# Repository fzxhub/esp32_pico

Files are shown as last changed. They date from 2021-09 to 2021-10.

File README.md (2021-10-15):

# esp32_pico
这是一个使用esp32-pico-d4设计的迷你开发板

## 背景

这是根据[稚晖君的ESP32-PicoDK](https://github.com/peng-zhihui/ESP32-PicoDK)修改的esp32迷你开发板。

## 修改要点

1. 增加所有IO引出，由于板子非常mini，所以在背面设计表贴焊盘，需要使用这些特殊接口时，使用贴片2.54的插针引出后再使用即可。
2. 将CAN使用的插针改为VCC3.3V和GND管脚。然后将CANL和CANH在背面设计表贴焊盘引出，个人CAN使用较少，使用时贴片2.54的插针引出后再使用即可。
3. 修改两排插针之间间距为700mil，更加规范的间距，可以使用面包板等。

## 图片

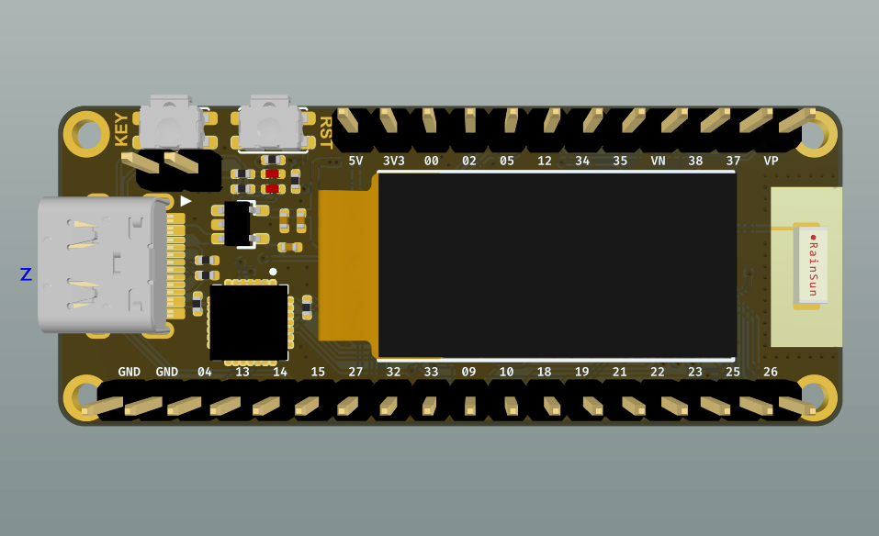
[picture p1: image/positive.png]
正面

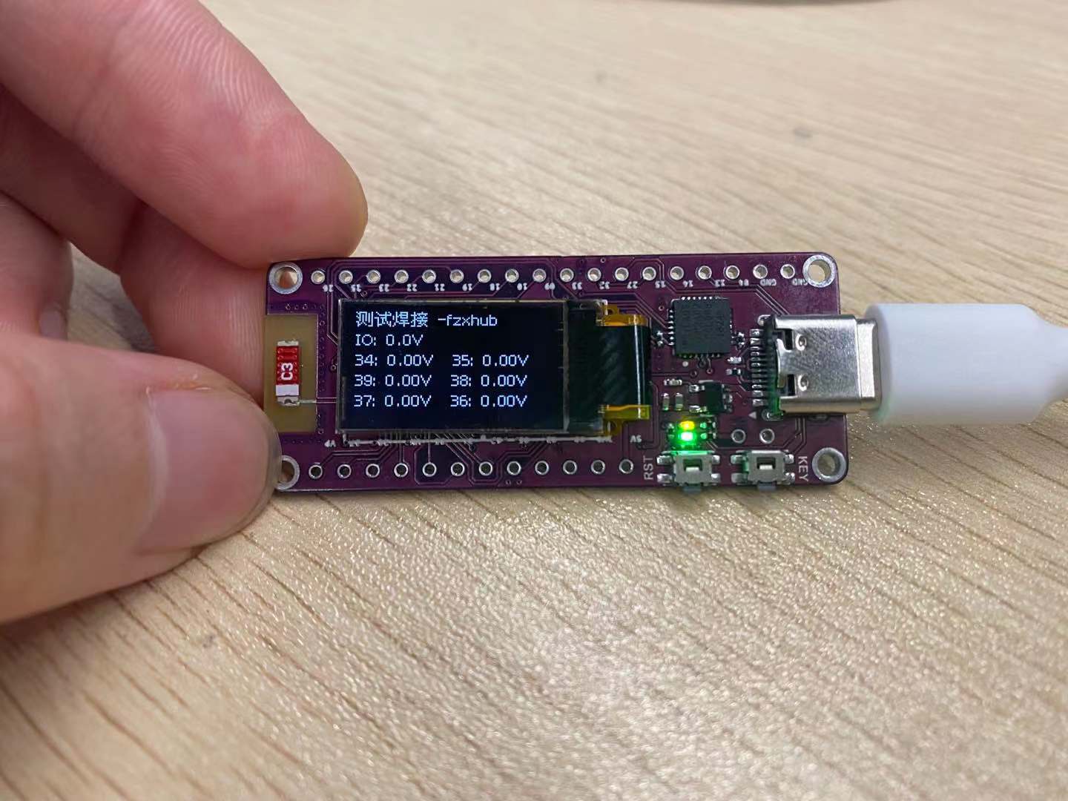
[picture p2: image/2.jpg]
实物


## firmware说明

esp32_pico_test固件是用来测试焊接是否OK的，esp32-pico-d4芯片手工焊接有点难度，需要验证所有IO可以使用。

1. 可以烧录固件表示cp2102，串口IO口：UTX、URX可以使用
2. OLED点亮，表示IO21、IO22可以使用
3. 34，35，39(VN)，38，37，36(VP)只能作为输入，接入模拟信号，屏幕上可以显示电压值
4. 其他IO定时反转，使用万用表可以测量，有定时反转表示OK
5. IO16、IO17、IO11、IO6、IO7、IO8特殊功能不加入测试

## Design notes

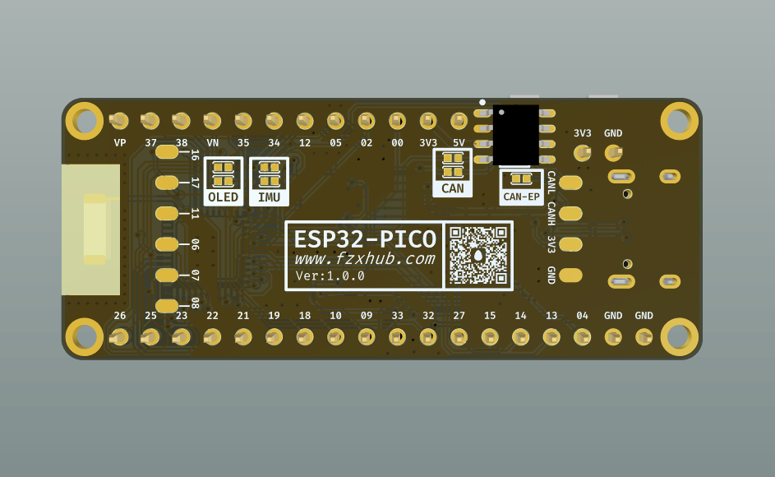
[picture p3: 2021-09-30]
image/reverse.png

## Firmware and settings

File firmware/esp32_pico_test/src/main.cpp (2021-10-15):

#include <Arduino.h>
#include <U8g2lib.h>
#include <Wire.h>

//u8g2库
U8G2_SSD1306_128X80_NONAME_F_HW_I2C u8g2(U8G2_R1, /* reset=*/ U8X8_PIN_NONE, /* clock=*/ 22, /* data=*/21);

//IO口，做输出
int allio[] = {0,2,5,12,4,13,14,15,27,32,33,9,10,18,19,23,25,26};
//I口，输入
int alli[] = {34,35,39,38,37,36};
//输出值
int value = 1;
//输出值反转计数标志
int time_flag = 0;

void setup(void)
{
    //u8g2库
    u8g2.begin();
    u8g2.enableUTF8Print(); 
    //IO口，做输出
    for(int i = 0; i < sizeof(allio)/sizeof(allio[0]); i++)
    {
        pinMode(allio[i], OUTPUT);
    } 
    //I口，输入
    for(int i = 0; i < sizeof(alli)/sizeof(alli[0]); i++)
    {
        pinMode(alli[i], INPUT);
    }
    //u8g2库设置
    u8g2.setFont(u8g2_font_wqy12_t_gb2312);
    u8g2.setFontDirection(0);
}

void loop(void)
{
    //清除缓存
    u8g2.clearBuffer();

    //显示标题
    u8g2.setCursor(0, 10);
    u8g2.print("测试焊接 -fzxhub"); 

    //计数
    time_flag++;
    if(time_flag >= 10) 
    {
        value = !value; 
        time_flag = 0;
    }

    //输出
    for(int i = 0; i < sizeof(allio)/sizeof(alli[0]); i++)
    {
        digitalWrite(allio[i],value);
    }
    if(value) 
    {
        u8g2.setCursor(0, 25);
        u8g2.print("IO: 3.3V");
    }
    else
    {
        u8g2.setCursor(0, 25);
        u8g2.print("IO: 0.0V");
    }

    //输出采集
    for(int i = 0; i < sizeof(alli)/sizeof(alli[0]); i = i+2)
    {
        u8g2.setCursor(0, i/2*15+40);
        u8g2.print(String(alli[i]) + ": " + (analogRead(alli[i])/4096.0*3.3) + "V" + "  " + String(alli[i+1]) + ": " + (analogRead(alli[i+1])/4096.0*3.3) + "V");
    }
    
    //显示
    u8g2.sendBuffer();
    
    delay(10);
}

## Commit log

2021-09-29 第一次上传硬件
    [esp32_pico.PrjPCB, esp32_pico.SchDoc]
2021-09-30 完成硬件，准备打样
    [esp32_pico.PrjPCB, esp32_pico.SchDoc]
2021-09-30 增加嘉立创打版编号位置
2021-10-12 增加gitgnore
2021-10-14 增加焊接BOM
2021-10-15 测试硬件OK，完成
2021-10-15 修改字符错位，重新打板
